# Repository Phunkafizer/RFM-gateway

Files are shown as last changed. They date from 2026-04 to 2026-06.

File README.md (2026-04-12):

<p align="center">
  
  
  
  
</p>

# RFM Gateway

RFM Gateway is a radio-to-WiFi bridge that connects HopeRF radio modules to an
ESP8266. It can receive RF data and forward it to your WiFi network, and it can
also send RF commands from HTTP or MQTT inputs.

Project description:
https://www.seegel-systeme.de/2023/09/15/rfm-wifi-gateway-a-radio-to-wifi-bridge/

Home Assistant forum:
https://community.home-assistant.io/t/rfm-gateway-a-sub-ghz-bridge-to-home-assistant/982886

## Highlights

- USB-C for power, flashing, and UART access
- Integrated USB programmer (no extra external programmer required)
- SMA antenna connector for the radio module
- Optional 0.96 inch I2C OLED support
- I2C and 1-wire extension headers

## Firmware capabilities

- 433 MHz RC pulse gateway (receive and transmit)
- 868 MHz sensor gateway (for supported sensor families)
- 868 MHz FS20 gateway
- Home Assistant integration via MQTT discovery

## Typical applications

- Bring wireless weather sensors into WiFi and MQTT
- Control RF sockets and remote controls
- Bridge RF nodes into home automation systems

## Repository structure

- [Firmware/](Firmware/): PlatformIO firmware project and web UI
- [PCB/](PCB/): hardware design files
- [assets/](assets/): screenshots and images

## Licensing

This repository uses a split-license model:

- Software/Firmware code: MIT, see [LICENSE](LICENSE)
- Hardware design files: CERN-OHL-S-2.0, see [LICENSE-HARDWARE](LICENSE-HARDWARE)
- Documentation and media assets: CC BY-SA 4.0, see [LICENSE-DOCS](LICENSE-DOCS)

### Preview

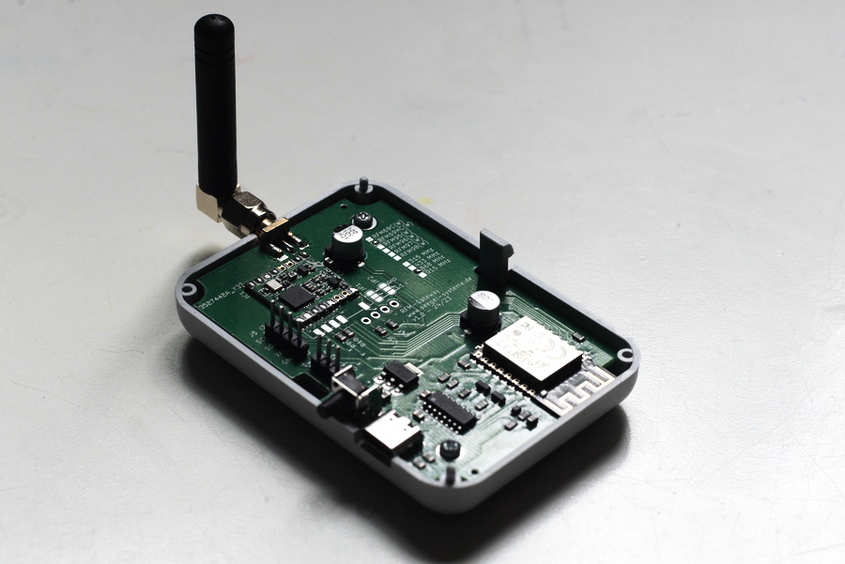
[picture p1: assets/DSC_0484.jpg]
RFM Gateway hardware

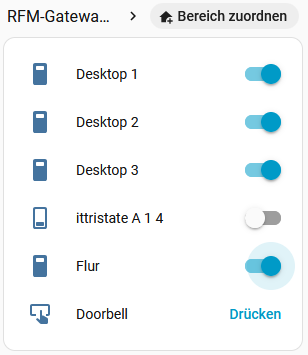
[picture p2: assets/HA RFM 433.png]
Home Assistant view

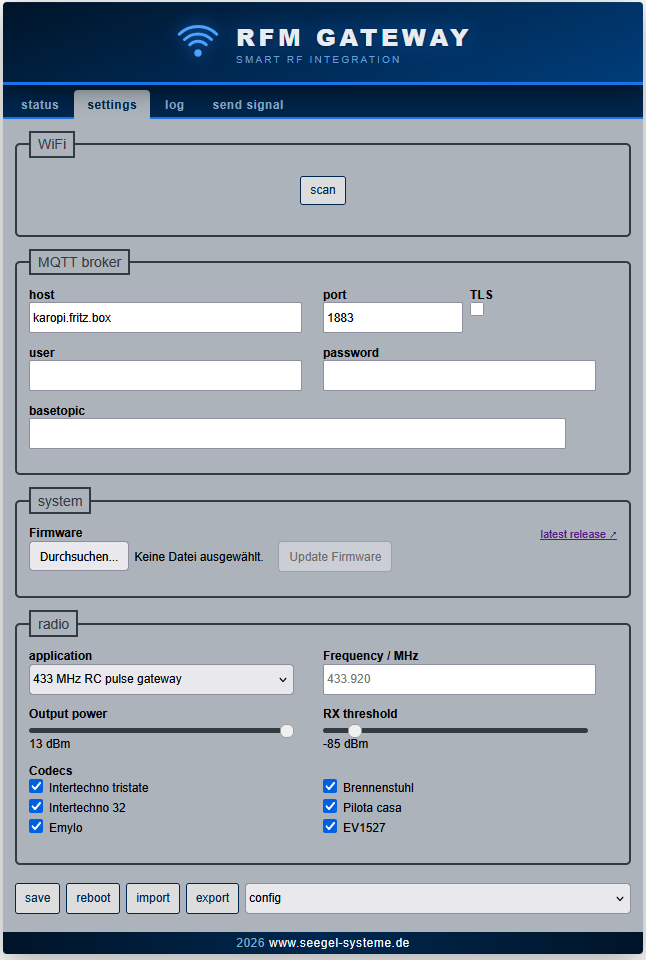
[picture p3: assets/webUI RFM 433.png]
Web UI view


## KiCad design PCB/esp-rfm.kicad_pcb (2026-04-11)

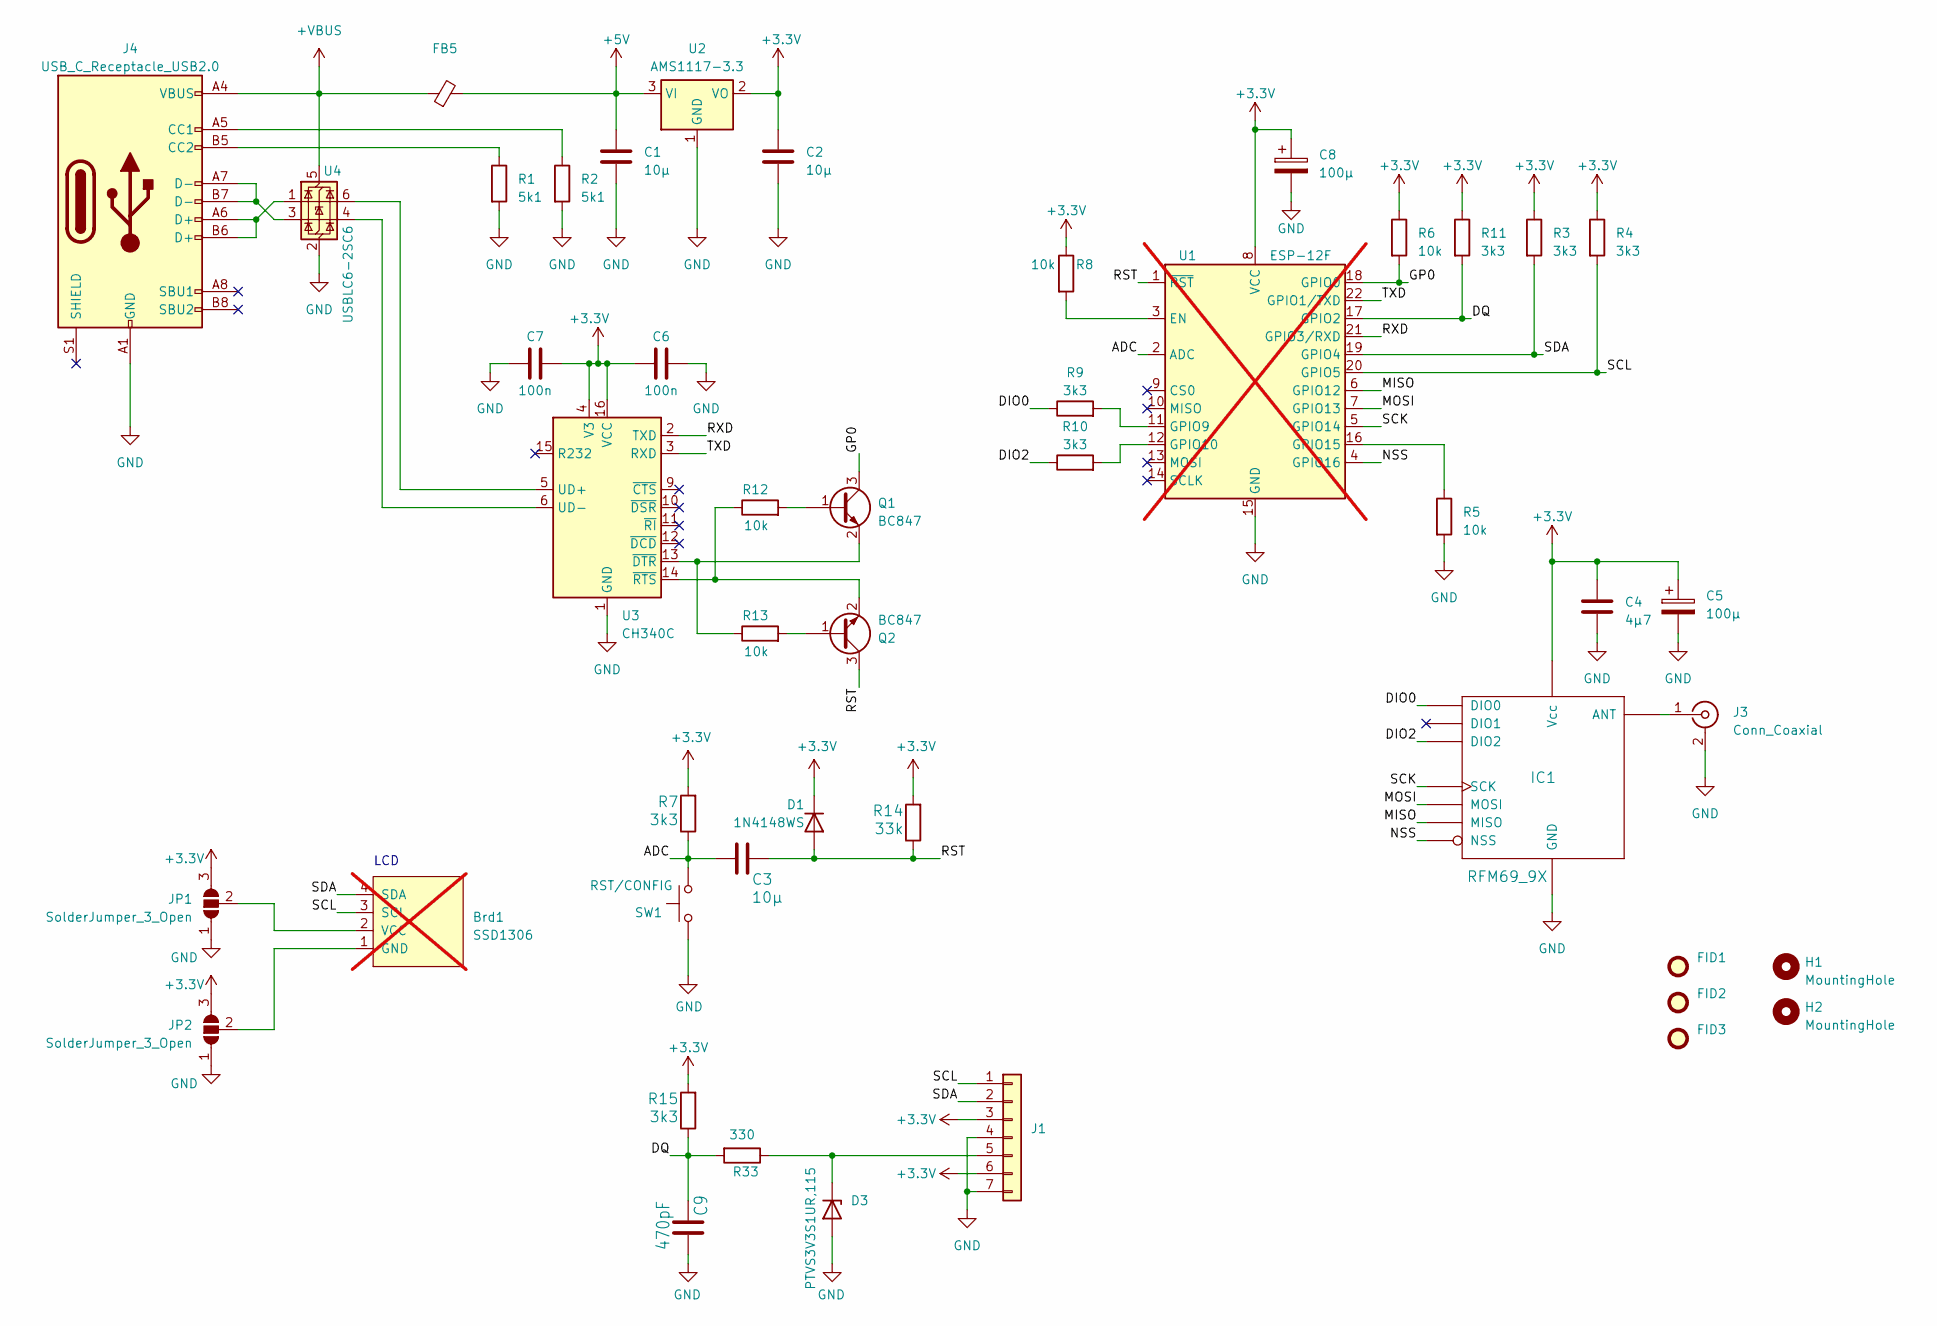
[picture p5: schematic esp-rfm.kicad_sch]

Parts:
Brd1: SSD1306; 128x64OLED; not fitted
C1, C2: 10µ; C_0805_2012Metric; LCSC C90543
C3: 10µ; C_0805_2012Metric; LCSC C15850
C4: 4µ7; C_0805_2012Metric; LCSC C319192
C5, C8: 100µ; CP_Elec_6.3x5.4; LCSC C59937
C6, C7: 100n; C_0805_2012Metric; LCSC C344180
C9: 470pF; C_0805_2012Metric; LCSC C62771
D1: 1N4148WS; D_SOD-323; LCSC C57759
D3: PTVS3V3S1UR,115; D_SOD-123; LCSC C183521
FB5: L_0603_1608Metric; LCSC C1002
FID1, FID2, FID3: Fiducial_1mm_Mask2mm
H1, H2: MountingHole; MountingHole_2.5mm_Pad
IC1: RFM69_9X
J1: PinHeader_1x07_P2.54mm_Vertical; LCSC C32713273
J3: Conn_Coaxial; SMA_H
J4: USB_C_Receptacle_USB2.0; USB_C_Receptacle_G-Switch_GT-USB-7010ASV; LCSC C2927037
JP1, JP2: SolderJumper_3_Open; SolderJumper-3_P1.3mm_Open_RoundedPad1.0x1.5mm
Q1, Q2: BC847; SOT-23; LCSC C181141
R1, R2: 5k1; R_0805_2012Metric; LCSC C431925
R3, R4, R7, R9, R10, R11, R15: 3k3; R_0805_2012Metric; LCSC C26010
R5, R6, R8, R12, R13: 10k; R_0805_2012Metric; LCSC C110775
R14: 33k; R_0805_2012Metric; LCSC C17633
R33: 330; R_0805_2012Metric; LCSC C17630
SW1: RST/CONFIG; SW_Tactile_SPST_Angled_PTS645Vx39-2LFS; LCSC C2837540
U1: ESP-12F; ESP-12E; LCSC C82891; not fitted
U2: AMS1117-3.3; SOT-223-3_TabPin2; LCSC C351784
U3: CH340C; SOIC-16_3.9x9.9mm_P1.27mm; LCSC C84681
U4: USBLC6-2SC6; SOT-23-6; LCSC C2827654

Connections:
+3.3V: C2.1, C4.1, C5.1, C6.1, C7.2, C8.1, D1.1 (K), IC1.Vcc, J1.3, J1.6, JP1.3 (B), JP2.3 (B), R3.1, R4.1, R6.1, R7.2, R8.1, R11.1, R14.2, R15.2, U1.8 (VCC), U2.2 (VO), U3.4 (V3), U3.16 (VCC)
+5V: C1.1, FB5.2, U2.3 (VI)
+VBUS: FB5.1, J4.A4 (VBUS), J4.A9 (VBUS), J4.B4 (VBUS), J4.B9 (VBUS), U4.5 (VBUS)
/ADC: C3.2, R7.1, SW1.1, U1.2 (ADC)
/DIO0: IC1.DIO0, R9.1
/DIO2: IC1.DIO2, R10.1
/DQ: C9.1, R11.2, R15.1, R33.2, U1.17 (GPIO2)
/GP0: Q1.3 (C), R6.2, U1.18 (GPIO0)
/MISO: IC1.MISO, U1.6 (GPIO12)
/MOSI: IC1.MOSI, U1.7 (GPIO13)
/NSS: IC1.NSS, U1.4 (GPIO16)
/RST: C3.1, D1.2 (A), Q2.3 (C), R14.1, U1.1 (~RST)
/RXD: U1.21 (GPIO3/RXD), U3.2 (TXD)
/SCK: IC1.SCK, U1.5 (GPIO14)
/SCL: Brd1.3 (SCL), J1.1, R4.2, U1.20 (GPIO5)
/SDA: Brd1.4 (SDA), J1.2, R3.2, U1.19 (GPIO4)
/TXD: U1.22 (GPIO1/TXD), U3.3 (RXD)
GND: C1.2, C2.2, C4.2, C5.2, C6.2, C7.1, C8.2, C9.2, D3.2 (A), IC1.2.1 (GND), IC1.2.8 (GND), IC1.2.10 (GND), IC1.GND, J1.4, J1.7, J3.2 (Ext), J4.A1 (GND), J4.A12 (GND), J4.B1 (GND), J4.B12 (GND), JP1.1 (A), JP2.1 (A), R1.2, R2.2, R5.2, SW1.2, U1.15 (GND), U2.1 (GND), U3.1 (GND), U4.2 (GND)
unnamed: Brd1.1 (GND), JP2.2 (C)
unnamed: Brd1.2 (VCC), JP1.2 (C)
unnamed: D3.1 (K), J1.5, R33.1
unnamed: IC1.ANT, J3.1 (In)
unnamed: J4.A5 (CC1), R2.1
unnamed: J4.B5 (CC2), R1.1
unnamed: J4.A6 (D+), J4.B6 (D+), U4.1 (I/O1)
unnamed: J4.A7 (D-), J4.B7 (D-), U4.3 (I/O2)
unnamed: Q1.1 (B), R12.2
unnamed: Q1.2 (E), R13.1, U3.13 (~DTR)
unnamed: Q2.1 (B), R13.2
unnamed: Q2.2 (E), R12.1, U3.14 (~RTS)
unnamed: R8.2, U1.3 (EN)
unnamed: R9.2, U1.11 (GPIO9)
unnamed: R10.2, U1.12 (GPIO10)
unnamed: R5.1, U1.16 (GPIO15)
unnamed: U3.5 (UD+), U4.6 (I/O1)
unnamed: U3.6 (UD-), U4.4 (I/O2)

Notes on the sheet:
LCD

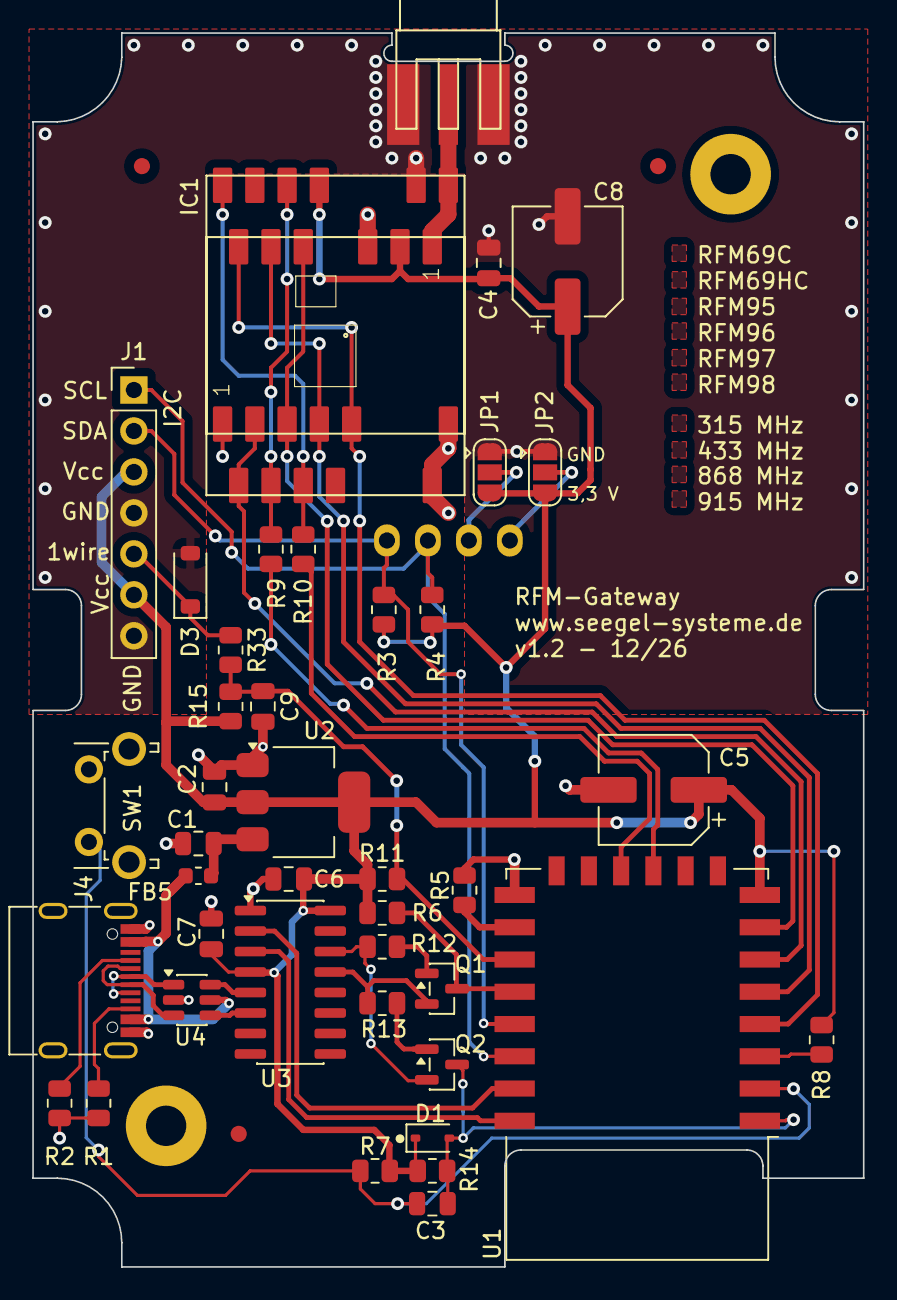
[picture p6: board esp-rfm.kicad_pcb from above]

Board: 2 copper layers, 51.5 x 76.5 mm, 47 parts (1 on the bottom side), 36 nets.

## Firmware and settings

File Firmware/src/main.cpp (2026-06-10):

#include <Arduino.h>
#include <ESP8266WiFi.h>
#include <ESP8266mDNS.h>
#include <LittleFS.h>
#include <ArduinoJson.h>
#include <DNSServer.h>
#include <Ticker.h>
#include "main.h"
#include "applications/868gw.h"
#include "applications/fs20.h"
#include "applications/rc433.h"
#include "html.h"
#include "global.h"
#include "HADiscLocal.h"


enum RfmType : uint8_t {
    RFM_TYPE_RFM69xx = 0,
    RFM_TYPE_RFM69Hxx = 1,
    RFM_TYPE_RFM95 = 2,
    RFM_TYPE_RFM96 = 3,
    RFM_TYPE_RFM97 = 4,
    RFM_TYPE_RFM98 = 5
};

enum FreqBand : uint8_t {
    FREQ_BAND_315 = 0,
    FREQ_BAND_433 = 1,
    FREQ_BAND_868 = 2,
    FREQ_BAND_915 = 3
};

PGM_P APP_JSON PROGMEM = "application/json";

static const char FILE_RADIO[] PROGMEM = "radio.json";
static const char FILE_CONFIG[] PROGMEM = "config.json";
static const char HOSTNAME[] PROGMEM = "rfm-gateway";
static const char STR_AP_NAME[] PROGMEM = AP_NAME;
static const char STR_AP_PASS[] PROGMEM = AP_PASS;
static const IPAddress apAddress(4, 3, 2, 1);
static const IPAddress apSubnet(255, 255, 255, 0);
static const uint16_t WEBPORT = 80;
static const uint8_t DNS_PORT = 53;
static const int MQTT_RETRY_INTERVAL_MS = 5000;

AsyncWebServer websrv(WEBPORT);
AsyncWebSocket ws("/ws");
WiFiClient espClient;
WiFiClientSecure espSecClient;
PubSubClient mqtt;
bool rebootFlag = false;
DNSServer dnsServer;
String hostname;
String mqttHost;
String mqttUser;
String mqttPass;
String baseTopic;
uint32_t mqttNextReconnectAt = 0;

Rfm69 *rfm69 = nullptr;

Ticker ledblink;
uint16_t leddata = 0x8000;

JsonDocument discJson;
bool startMdnsFlag = false;
bool startMdnsApFlag = false;
bool mdnsStarted = false;
uint32_t nextMdnsRetryAt = 0;

String getAvailabilityTopic() {
    return baseTopic + F("/status");
}

void ledTickcb() {
    static uint16_t mask = 0x8000;

    digitalWrite(LED_BUILTIN, (leddata & mask) == 0);
    mask >>= 1;
    if (!mask)
        mask = 0x8000;
}

bool startMdns() {
    if (mdnsStarted) {
        SDBGLN("mDNS already started");
        return true;
    }

    if (hostname.isEmpty())
        hostname = FPSTR(HOSTNAME);
    
    mdnsStarted = true;
    
    // Don't close if already running - just restart the service
    if (!MDNS.begin(hostname.c_str())) {
        MDNS.close();
        if (!MDNS.begin(hostname.c_str())) {
            mdnsStarted = false;
            return false;
        }
    }
    
    MDNSResponder::hMDNSService hService = MDNS.addService(hostname.c_str(), "http", "tcp", WEBPORT);
    if (hService) {
        MDNS.addServiceTxt(hService, "rf_api", "1");
        MDNS.addServiceTxt(hService, "model", "rfm-gateway");
        MDNS.update();
    } else {
        mdnsStarted = false;
    }
    return true;
}

bool loadRadioSetup() {
    bool result = false;
    File f = LittleFS.open(FPSTR(FILE_RADIO), "r");
    if (f) {
        JsonDocument cfg;
        if (deserializeJson(cfg, f) == DeserializationError::Ok) {
            if (rfm69 != nullptr)
                delete rfm69;

            switch (cfg[F("rfmType")].as<int>()) {
            case RFM_TYPE_RFM69xx:
                rfm69 = new Rfm69;
                rfm69->begin(16, false);
                result = true;
                break;

            case RFM_TYPE_RFM69Hxx:
                rfm69 = new Rfm69;
                rfm69->begin(16, true);
                result = true;
                break;

            default:
                break;
            }

            if (rfm69 != nullptr)
                rfm69->setFCorr(cfg[F("fCorr")]);
        }
        f.close();
    }
    return result;
}

void setConfig(const JsonObject &obj) {
    if (!obj[F("hostname")].isNull()) {
        hostname = obj[F("hostname")].as<String>();
        WiFi.setHostname(hostname.c_str());

        if (WiFi.localIP().isSet())
            startMdns();
    }

    if (!obj[F("mqtt")].isNull()) {
        const JsonObject &jMqtt = obj[F("mqtt")];
        if (mqtt.connected())
            mqtt.disconnect();

        if (jMqtt[F("tls")].as<bool>()) {
            espSecClient.setInsecure();
            mqtt.setClient(espSecClient);
        }
        else
            mqtt.setClient(espClient);

        mqttHost = jMqtt[F("host")].as<String>();
        mqttUser = jMqtt[F("user")].as<String>();
        mqttPass = jMqtt[F("pass")].as<String>();
        if (!jMqtt[F("basetopic")].isNull())
            baseTopic = jMqtt[F("basetopic")].as<String>();
        if (baseTopic.isEmpty())
            baseTopic = F("home/rfm-gateway");

        mqtt.setServer(mqttHost.c_str(), jMqtt[F("port")] | 1883);
        mqtt.setBufferSize(1024);
        mqttNextReconnectAt = 0;
    }

    if (!obj[F("application")].isNull()) {
        if (radioapp != nullptr) {
            delete radioapp;
            radioapp = nullptr;
        }

        JsonObject appSettings = obj[F("appSettings")];

        switch (obj[F("application")].as<int>()) {
        case 0:
            if (rfm69 != nullptr)
                radioapp = new Rc433Transceiver(appSettings);
            break;
        case 1:
            if (rfm69 != nullptr)
                radioapp = new Gw868(appSettings);
            break;
        case 2:
            if (rfm69 != nullptr)
                radioapp = new FS20(appSettings);
            break;

        default:
            break;
        }
    }

    if (rfm69 != nullptr) {
        const int8_t pwr = obj[F("txPwr")] | 13;
        rfm69->setTxPower(pwr);
        const int8_t rxThresh = obj[F("rxThresh")] | -70;
        rfm69->setRxThresh(rxThresh);
        if (radioapp != nullptr)
            if (obj[F("rffreq")].is<double>()) {
                uint32_t freq = obj[F("rffreq")].as<float>() * 1e6;
                radioapp->setFreq(freq);
            }
            radioapp->restartReceive();
    }
}

void onWsEvent(AsyncWebSocket *server, AsyncWebSocketClient *client, AwsEventType type, void *arg, uint8_t *data, size_t len) {
    (void) server;
    (void) client;
    (void) arg;
    (void) data;
    (void) len;
    switch (type) {
        case WS_EVT_CONNECT:
            //Serial.printf("WebSocket client #%u connected from %s\n", client->id(), client->remoteIP().toString().c_str());
            break;
        case WS_EVT_DISCONNECT:
            //Serial.printf("WebSocket client #%u disconnected\n", client->id());
            break;
        case WS_EVT_DATA:
            //handleWebSocketMessage(arg, data, len);
            break;
        case WS_EVT_PONG:
        case WS_EVT_ERROR:
            break;
    }
}

void wiFiEvent(WiFiEvent_t event) {
    if (event == 7)
        return;

    SDBG("wiFiEvent ");
    SDBGLN((int) event);

    // Defer mDNS (re)start to loop context when STA gets an IP.
    if (event == WIFI_EVENT_STAMODE_GOT_IP) {
        if (hostname.isEmpty())
            hostname = FPSTR(HOSTNAME);
        WiFi.setHostname(hostname.c_str());
        startMdnsFlag = true;
    }

    if (event == WIFI_EVENT_STAMODE_DISCONNECTED) {
    }
}

void mqttCallback(const char topic[], byte* payload, unsigned int length) {
    if (radioapp != nullptr) {
        String sTop(topic);
        sTop = sTop.substring(baseTopic.length() + 1);
        String sPayload;
        sPayload.concat((const char*) payload, length);
        ws.textAll(F("<div class='rfframe'>"));
        ws.textAll(F("Rec. MQTT ~/") + sTop + ": " + sPayload);
        radioapp->onMqttMessage(sTop, sPayload);
        ws.textAll(F("</div>"));
    }
}

void setup() {
    pinMode(LED_BUILTIN, OUTPUT); // ESP12 LED, GPIO2 also used for 1wire
    digitalWrite(LED_BUILTIN, HIGH);
    
    ledblink.attach(0.1, ledTickcb);

    bool apMode = false;
    #ifdef DEBUG
        apMode = true;
    #endif
    LittleFS.begin();

    while (analogRead(A0) < 512) {
        yield();
        if (millis() > 2000) {
            apMode = true;
            leddata = 0xA000;
            if (millis() > 10000) { // factory reset
                ledblink.detach();
                LittleFS.remove(FPSTR(FILE_CONFIG));
                LittleFS.end();
                WiFi.disconnect(true);
                ESP.eraseConfig();
                digitalWrite(LED_BUILTIN, LOW);
                while (analogRead(A0) < 512)
                    yield();
                ESP.reset();
                while (true);
            }
        }
    }

    Serial.begin(76800);
    SPI.begin();

    hostname = FPSTR(HOSTNAME);
    
    if (!loadRadioSetup())
        apMode = true;

    if (apMode) {
        leddata = 0xA000;
        WiFi.persistent(false);
        WiFi.softAPConfig(apAddress, apAddress, apSubnet);
        WiFi.softAP(FPSTR(STR_AP_NAME), FPSTR(STR_AP_PASS));
        WiFi.mode(WIFI_AP_STA);
        dnsServer.start(DNS_PORT, "*", apAddress);
        dnsServer.processNextRequest();
        // In AP+STA mode, delay mDNS startup until STA has an IP.
        // Starting on AP first can prevent expected LAN discovery behavior.
        startMdnsApFlag = false;
    }

    File f = LittleFS.open(FPSTR(FILE_CONFIG), "r");
    if (f) {
        JsonDocument cfg;
        if (deserializeJson(cfg, f) == DeserializationError::Ok)
            setConfig(cfg.as<JsonObject>());
        f.close();
    }

    if (hostname.isEmpty())
        hostname = FPSTR(HOSTNAME);

    WiFi.setHostname(hostname.c_str());
    WiFi.onEvent(wiFiEvent);
    WiFi.begin();

    discJson.set(nullptr);
    
    websrv.begin();
    ws.onEvent(onWsEvent);
    websrv.addHandler(&ws);
    websrv.on("/", HTTP_GET, [](AsyncWebServerRequest *request) {
        #ifdef DEBUG
        if (LittleFS.exists(F("/index.html"))) {
            request->send(LittleFS, F("/index.html"), F("text/html"));
            return;
        }
        #endif
        request->send_P(200, F("text/html"), html);
    });

    websrv.on(PSTR("/scan"), HTTP_GET, [](AsyncWebServerRequest *request) {
        JsonDocument doc;
        JsonObject jobj = doc.to<JsonObject>();

        int n = WiFi.scanComplete();
        jobj[F("status")] = n;
        if (n == -2)
            WiFi.scanNetworks(true);
        else
            if (n >= 0) {
                JsonArray results = jobj[F("results")].to<JsonArray>();
                for (int i=0; i<n; i++) {
                    JsonObject result = results.add<JsonObject>();
                    result[F("ssid")] = WiFi.SSID(i);
                    result[F("rssi")] = WiFi.RSSI(i);
                    result[F("channel")] = WiFi.channel(i);
                }
                WiFi.scanDelete();
            }

        AsyncResponseStream *response = request->beginResponseStream(FPSTR(APP_JSON));
        serializeJson(doc, *response);
        request->send(response);
    });

    websrv.on(PSTR("/setwifi"), HTTP_POST, [] (AsyncWebServerRequest *request) {
        if (request->hasArg(F("ssid")) && request->hasArg(F("pass"))) {
            request->send(200);

            String ssid = request->arg(F("ssid"));
            String pass = request->arg(F("pass"));

            WiFi.disconnect();
            WiFi.persistent(true);
            WiFi.begin(ssid, pass);
            WiFi.setAutoConnect(false); // connect on power on
            WiFi.setAutoReconnect(true);
        }
        else
            request->send(400); // bad request
    });

    websrv.on(PSTR("/status"), HTTP_GET, [](AsyncWebServerRequest *request) {
        JsonDocument doc;

        JsonObject jWifi = doc[F("WiFi")].to<JsonObject>();
        jWifi[F("status")] = WiFi.status();
        jWifi[F("ipsta")] = WiFi.localIP().toString();
        jWifi[F("mac")] = WiFi.macAddress();
        jWifi[F("hostname")] = WiFi.getHostname();
        jWifi[F("sta_ssid")] = WiFi.SSID();

        JsonObject jSystem = doc[F("system")].to<JsonObject>();
        jSystem[F("uptime")] = millis() / 1000;
        jSystem[F("freeHeap")] = ESP.getFreeHeap();
        jSystem[F("firmware")] = F(BUILD_VERSION);

        JsonObject jMqtt = doc[F("mqtt")].to<JsonObject>();
        jMqtt[F("state")] = mqtt.state();
        jMqtt[F("connected")] = mqtt.connected();

        AsyncResponseStream *response = request->beginResponseStream(FPSTR(APP_JSON));
        serializeJson(doc, *response);
        request->send(response); });

    websrv.on(PSTR("/config"), HTTP_GET, [](AsyncWebServerRequest *request) {
        JsonDocument doc;
        doc.to<JsonObject>();

        File fRadio = LittleFS.open(FPSTR(FILE_RADIO), "r");
        if (fRadio) {
            JsonDocument radio;
            if (deserializeJson(radio, fRadio) == DeserializationError::Ok)
                doc[F("radio")] = radio;
            fRadio.close();
        }

        File fCfg = LittleFS.open(FPSTR(FILE_CONFIG), "r");
        if (fCfg) {
            JsonDocument cfg;
            if (deserializeJson(cfg, fCfg) == DeserializationError::Ok)
                doc["config"] = cfg;
            fCfg.close();
        }

        AsyncResponseStream *response = request->beginResponseStream(FPSTR(APP_JSON));
        serializeJson(doc, *response);
        request->send(response); 
    });

    websrv.on(PSTR("/config"), HTTP_POST, 
        [] (AsyncWebServerRequest *request) {(void) request;}, 
        [] (AsyncWebServerRequest *request, const String &filename, size_t index, uint8_t *data, size_t len, bool final) {
            (void) request;
            (void) filename;
            (void) index;
            (void) data;
            (void) len;
            (void) final;
        }, 
        [] (AsyncWebServerRequest *request, uint8_t *data, size_t len, size_t index, size_t total) {
        static String confBuf;
        if (!index)
            confBuf.clear();

        confBuf.concat((const char*) data, len);
        if (confBuf.length() != total)
            return;

        JsonDocument doc;
        if (deserializeJson(doc, confBuf) == DeserializationError::Ok) {
            if (!doc[F("radio")].isNull()) {
                File f = LittleFS.open(FPSTR(FILE_RADIO), "w");
                serializeJson(doc[F("radio")], f);
                f.close();
                loadRadioSetup();
            }

            if (!doc[F("config")].isNull()) {
                File f = LittleFS.open(FPSTR(FILE_CONFIG), "w");
                serializeJson(doc[F("config")], f);
                f.close();
                setConfig(doc[F("config")]);
            }
            request->send(200);
        }
        else {
            request->send(400);
        }
        confBuf.clear();
    });

    websrv.on(PSTR("/txtest"), HTTP_POST, [](AsyncWebServerRequest *request) {
            (void) request;
        }, 
        [](AsyncWebServerRequest *request, const String &filename, size_t index, uint8_t *data, size_t len, bool final) {
            (void) request;
            (void) filename;
            (void) index;
            (void) data;
            (void) len;
            (void) final;
        }, [](AsyncWebServerRequest *request, uint8_t *data, size_t len, size_t index, size_t total) {
            (void) index;
            (void) total;

        request->send(200);

        JsonDocument doc;
        deserializeJson(doc, (char*) data, len);

        if (rfm69 != nullptr) {
            delete rfm69;
            rfm69 = nullptr;
        }

        uint8_t rfmtype = doc[F("rfmType")].as<uint8_t>();
        switch (rfmtype) {
        case RFM_TYPE_RFM69xx:
            rfm69 = new Rfm69();
            rfm69->begin(16, false);
            break;
        case RFM_TYPE_RFM69Hxx:
            rfm69 = new Rfm69();
            rfm69->begin(16, true);
            break;
        default: 
            break;
        }

        if (rfm69 != nullptr) {
            rfm69->txTest(
                doc[F("freq")].as<uint32_t>(),
                doc[F("fCorr")].as<int16_t>(), 
                doc[F("pwr")].as<int8_t>(),
                doc[F("baud")].as<uint16_t>()
            );
        }
    });

    websrv.on(PSTR("/senddisc"), HTTP_POST, 
        [] (AsyncWebServerRequest *request) { // onRequest handler
            (void) request;
        },
        [](AsyncWebServerRequest *request, const String &filename, size_t index, uint8_t *data, size_t len, bool final) {
            // onUpload handler
            (void) request;
            (void) filename;
            (void) index;
            (void) data;
            (void) len;
            (void) final;
        },
        [] (AsyncWebServerRequest *request, uint8_t *data, size_t len, size_t index, size_t total) {
             // onBody handler
            (void) request;
            (void) data;
            (void) len;

            if (!discJson.isNull()) {
                request->send(400);
                return;
            }

            static String buf;

            if (index == 0)
                buf.clear();

            buf.concat((const char*) data, len);
            if (buf.length() != total)
                return;

            if (deserializeJson(discJson, buf) == DeserializationError::Ok) {
                request->send(200);
            }
            else {
                request->send(400);
            }   
            buf.clear(); 
    });

    websrv.on(PSTR("/update"), HTTP_POST, 
        [] (AsyncWebServerRequest *request) { // onRequest handler
            int httpRes;

            rebootFlag = !Update.hasError();
            if (rebootFlag)
                httpRes = 200;
            else
            httpRes = 500;

            AsyncWebServerResponse *response = request->beginResponse(httpRes);
            response->addHeader(F("Connection"), F("close"));
            request->send(response);
        },
        [] (AsyncWebServerRequest *request, const String &filename, size_t index, uint8_t *data, size_t len, bool final) { // onUpdate handler
            (void) request;
            (void) filename;
            if (!index) {
                Update.runAsync(true);
                Update.begin(request->contentLength(), U_FLASH);
            }
            Update.write(data, len);
            if (final) {
                Update.end(true);
            }
        }
    );

    websrv.on(PSTR("/reboot"), HTTP_GET, [](AsyncWebServerRequest *request) {
        request->send(200);
        rebootFlag = true;
    });

    websrv.on(PSTR("/tabs"), HTTP_GET, [](AsyncWebServerRequest *request) {
        if (radioapp != nullptr && radioapp->html != nullptr)
            request->send_P(200, F("text/html"), radioapp->html);
        else
            request->send(404);
    });

    websrv.on(PSTR("/regdump"), HTTP_GET, [](AsyncWebServerRequest *request) {
        if (!rfm69) {
            request->send(404);
            return;
        }

        String result;
        for (uint8_t reg= 0x00; reg <= 0x4F; reg++) {
            uint8_t val = rfm69->readReg(reg);
            result += String(reg, HEX) + ": " + String(val, HEX) + "<br>";
        }
        request->send(200, "text", result);
    });

    websrv.onNotFound([](AsyncWebServerRequest *request) {
        request->send(404);
    });

    mqtt.setCallback(mqttCallback);
    haDisc.begin();
}


void loop() {
    const uint32_t nowMs = millis();

    if (startMdnsFlag) {
        startMdnsFlag = false;

        // In AP+STA mode, mDNS may have been started on AP first.
        // Rebind by closing and restarting once STA has an IP.
        if (mdnsStarted) {
            MDNS.close();
            mdnsStarted = false;
        }

        if (startMdns()) {
            MDNS.notifyAPChange();
            MDNS.update();
        }

        nextMdnsRetryAt = nowMs + 5000;
    }
    
    if (startMdnsApFlag) {
        startMdnsApFlag = false;
        startMdns();
        nextMdnsRetryAt = nowMs + 5000;
    }

    // Fallback for cases where Wi-Fi events are missed or mDNS start fails transiently.
    if (WiFi.localIP().isSet() && !mdnsStarted) {
        if ((int32_t) (nowMs - nextMdnsRetryAt) >= 0) {
            if (startMdns()) {
                MDNS.notifyAPChange();
                MDNS.update();
            }
            nextMdnsRetryAt = nowMs + 5000;
        }
    } else if (!WiFi.localIP().isSet()) {
        nextMdnsRetryAt = 0;
    }

    MDNS.update();
    mqtt.loop();

    if (WiFi.localIP().isSet()) {
        const uint32_t now = millis();
        if (!mqttHost.isEmpty() && !mqtt.connected() && (mqttNextReconnectAt == 0 || (int32_t) (now - mqttNextReconnectAt) >= 0)) {
            String id = WiFi.macAddress();

            id.remove(0, 9);
            int idx;
            while ( (idx = id.indexOf(':')) >= 0)
                id.remove(idx, 1);

            id = String(FPSTR(HOSTNAME)) + id;

            String statusTopic = baseTopic + F("/status");
            bool con = mqtt.connect(
                id.c_str(), 
                mqttUser.c_str(), 
                mqttPass.c_str(),
                statusTopic.c_str(),
                1,
                true,
                "offline"
            );
            if (con) {
                mqttNextReconnectAt = 0;
                mqtt.publish(statusTopic.c_str(), "online", true);
                String subtopic = baseTopic + F("/#");
                mqtt.subscribe(subtopic.c_str());
                ws.textAll(F("MQTT connected"));
            }
            else {
                mqttNextReconnectAt = now + MQTT_RETRY_INTERVAL_MS;
                ws.textAll(F("MQTT failure") + String(mqtt.state()));
            }
        }
    }

    if (rfm69 != nullptr) {
        rfm69->loop();
        if (radioapp != nullptr)
            radioapp->loop();
    }

    if (!discJson.isNull()) {
        if ( (radioapp != nullptr) && mqtt.connected())
            radioapp->sendDiscovery(discJson);
        discJson.set(nullptr);
    }

    if (rebootFlag) {
        delay(500);
        ESP.restart();
    }
}

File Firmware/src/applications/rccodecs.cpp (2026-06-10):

#include "rccodecs.h"
#include "main.h"
#include "HADiscLocal.h"
#include "radioapplication.h"

const uint16_t BITRATE = 20000;
const uint16_t PULSEWIDTHUS = 1000000UL / BITRATE; // samplingtime of tranceiver / µS

static const char STR_PROTOCOL[] PROGMEM = "protocol";
static const char STR_ID[] PROGMEM = "id";
static const char STR_COMMAND[] PROGMEM = "command";
static const char STR_HOUSE[] PROGMEM = "house";
static const char STR_ADDRESS[] PROGMEM = "address";
static const char STR_CHANNEL[] PROGMEM = "channel";
static const char STR_GROUP[] PROGMEM = "group";
static const char STR_DATA[] PROGMEM = "data";
static const char STR_KEY[] PROGMEM = "key";
static const char STR_TIMEBASE[] PROGMEM = "timebase";
static const char STR_ON[] PROGMEM = "ON";
static const char STR_OFF[] PROGMEM = "OFF";
static const char STR_EXT[] PROGMEM = "ext";
static const char STR_PRESS[] PROGMEM = "press";
static const char STR_ENCODING_ERROR[] PROGMEM ="encoding error!";

RcCodec* RcCodec::codecs = nullptr;
uint8_t RcCodec::symbolBuf[SYMBOLBUFSIZE];
uint8_t RcCodec::symbolBufLen;
uint16_t RcCodec::last_timebase = 0;

RcCodec::RcCodec():        
        next(codecs),
        lastDecode(0) {
    codecs = this;
    name = nullptr;
}

RcCodec::~RcCodec() {
    if (next) {
        free(next);
        next = nullptr;
    }
}

void RcCodec::freeCodecs() {
    if (codecs != nullptr)
        delete(codecs);
    codecs = nullptr;
}

bool RcCodec::decode(const uint8_t *pulseBuf, const uint8_t len) {
    bool decoded = false;
    RcCodec *codec = codecs;

    while (codec != nullptr) {
        if (codec->decodePulses(pulseBuf, len)) {
            if ( (codec->lastDecode < (millis() - 500)) || (memcmp(codec->localSymbolBuf, codec->symbolBuf, codec->symbolBufLen) != 0) ) {
                codec->onDecodedPulses();
            }

            memcpy(codec->localSymbolBuf, codec->symbolBuf, codec->symbolBufLen);
            codec->lastDecode = millis();
            decoded = true;
        }
        codec = codec->next;
    }
    return decoded;
}

uint8_t RcCodec::getTxRepeats() const {
    return params->txRepeats;
}

/**
 * @brief decodes given pulsebuf to symbols
 * Decoded symbols are saved in static variable "symbolBuffer"
 * number of decoded symbols is saved in static variable "symbolBufLen"
 */
void RcCodec::matchSymbols(const uint8_t *pulseBuf, const uint8_t len) {
    uint16_t timebase = params->timebase;
    symbolBufLen = 0;

    // automatic timebase calculation
    if (params->numSymbolsAutoTimebase > 0) {
        uint16_t sumPulses = 0;
        for (uint8_t i=0; i<params->numSymbolsAutoTimebase * params->pulsesPerSymbol; i++)
            sumPulses += pulseBuf[i];

        //calculate duration of a symbol, we always use 1st symbol in symTable
        uint8_t symDur = 0;
        for (uint8_t i=0; i<params->pulsesPerSymbol; i++)
            symDur += params->symbolTable[i];

        timebase = (uint32_t) sumPulses * PULSEWIDTHUS / params->numSymbolsAutoTimebase / symDur;
        if ( (timebase < params->timebase_min) || (timebase > params->timebase_max) )
            return;
    }
    last_timebase = timebase;

    const uint8_t SYMTAB_MAX = 32;
    static uint8_t symTabLow[SYMTAB_MAX];
    static uint8_t symTabHigh[SYMTAB_MAX];

    // calculate matching windows for pulses

    #ifdef DEBUGMATCHINGTABLES
    Serial.print("Matching table: ");
    #endif
    for (uint8_t s=0; s<params->numTableSymbols; s++) {
        for (uint8_t p=0; p<params->pulsesPerSymbol; p++) {
            uint8_t i = s * params->pulsesPerSymbol + p;
            
            // calculate matching windows in units of receiver's samplingtime
            symTabLow[i] = ((timebase * params->symbolTable[i] * (params->qDecode-1)) / params->qDecode + PULSEWIDTHUS / 2) / PULSEWIDTHUS;
            symTabHigh[i] = ((timebase * params->symbolTable[i] * (params->qDecode+1)) / params->qDecode + PULSEWIDTHUS / 2) / PULSEWIDTHUS;
            #ifdef DEBUGMATCHINGTABLES
            Serial.print(String(symTabLow[i]) + '-' + String(symTabHigh[i]) + ',');
            #endif
        }
    }
    #ifdef DEBUGMATCHINGTABLES
    Serial.println("");
    #endif

    uint8_t bp = 0;

    while (bp + params->pulsesPerSymbol <= len) {
        uint8_t s;

        #ifdef DEBUGRCDECODER
        Serial.print("Matching pulses ");
        for (uint8_t p=0; p<params->pulsesPerSymbol; p++)
            Serial.print(String(pulseBuf[bp+p]) + ' ');
        Serial.print(": ");
        #endif

        for (s=0; s<params->numTableSymbols; s++) {
            uint8_t p;

            for (p=0; p<params->pulsesPerSymbol; p++) {
                const uint8_t ist = s * params->pulsesPerSymbol + p; // calculate index in symboltable
                const uint8_t ipb = bp + p; // calculate index in pulse buffer
                if (ipb == 0) // skip very first pulse, it could be distorted by leading noise
                    continue;
                if ( (pulseBuf[ipb] < symTabLow[ist]) || (pulseBuf[ipb] > symTabHigh[ist]) ) {
                     //current pulse does not match to symbol to check, try matching next symbol
                    #ifdef DEBUGRCDECODER
                    Serial.print("!");
                    #endif
                    break;
                }
            }

            #ifdef DEBUGRCDECODER
            Serial.print("p " + String(p) + ", ");
            #endif

            if (p == params->pulsesPerSymbol) {
                // matching symbol found, continue with checking next pulses!
                break;
            }
            // check for next symbol
        }

        if (s == params->numTableSymbols) {
            //no matching symbol found
            break;
        }
        else {
            #ifdef DEBUGRCDECODER
            Serial.println("s " + String(s));
            #endif
            symbolBuf[symbolBufLen++] = s;
        }

        bp += params->pulsesPerSymbol;
    }
    #ifdef DEBUGSYMBOLBUF
    String str = F("Decoded symbols: ");
    for (uint8_t i=0; i<symbolBufLen; i++)
        str += char('0' + symbolBuf[i]);
    Serial.println(str);
    #endif
}

bool RcCodec::decodePulses(const uint8_t *pulseBuf, const uint8_t len, const uint8_t numSymbols) {
    const uint8_t ns = (numSymbols == 0) ? params->numSymbols : numSymbols;
    const uint8_t np = ns * params->pulsesPerSymbol;

    if (len < np + 2) // enough pulses in received buffer?
        return false;

    const uint8_t *buf = pulseBuf + len - np - 2;
    matchSymbols(buf, np);
    
    return (symbolBufLen == ns) && checkSymbolBuf();
}

bool RcCodec::checkSymbolBuf() {
    return true;
}

RcCodec* RcCodec::find(const String name) {
    RcCodec* codec = codecs;
    while (codec != nullptr) {
        if (codec->name != nullptr) {
            if (name.compareTo(codec->name) == 0)
                return codec;
        }
        codec = codec->next;
    }
    return nullptr;
}
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

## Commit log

2024-07-04 init commit
    [User Library-620-SMA-02-112-TGG SMA Female for PCB edge Mount.step, esp-rfm.kicad_pcb, esp-rfm.kicad_sch]
2024-08-19 add radio applications cleanup
    [esp-rfm.kicad_pcb, esp-rfm.kicad_sch]
2024-09-17 add slider for TX power fix RFM69 initialization
    [main.cpp, rccodecs.cpp, rfm.cpp]
2025-01-13 fix warning in platformio.ini
    status LED blinker
    update PCB
    [esp-rfm.kicad_pcb, esp-rfm.kicad_sch]
2025-02-10 add helpers & testtools fix radiomodel in webUI
    [main.cpp, rfm.cpp]
2026-01-29 fix FS20 codec add home assistant auto discovery add RX threshold setting
    [main.cpp]
2026-01-30 webUI add websocket status fix sync IT32
    [rccodecs.cpp]
2026-01-31 fix FS20 ext command add auto discovery buttons
    [main.cpp, rccodecs.cpp]
2026-02-03 fix pilota encoder
2026-02-04 HA auto discovery for 868 MHz sensors
2026-02-08 set HA availability show HA discovery button on send
2026-03-29 minify html before build testrfm: send default config fix RC433 codecs in webUI
    [main.cpp]
2026-04-11 add custom RX mode for 868 gateway add import / export to webUI add frequency setting
    [User Library-620-SMA-02-112-TGG SMA Female for PCB edge Mount.step]
2026-04-11 change pin header add ferrite
    [esp-rfm.kicad_pcb, esp-rfm.kicad_sch]
2026-04-11 add github action fix frequency setting
    [main.cpp]
2026-04-11 improve log visibility seperate command buttons
2026-04-12 show toast on discovery button add HA sensor for battery low eye candy

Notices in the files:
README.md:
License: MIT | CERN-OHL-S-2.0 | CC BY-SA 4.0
